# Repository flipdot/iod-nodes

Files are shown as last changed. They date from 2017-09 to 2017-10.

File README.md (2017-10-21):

# iod-nodes

ESP8266 based MQTT nodes controlled by Attiny.

This project covers battery powered WiFi devices running MQTT. The design goal was extremely low standby current for very long battery life.

The Attiny 25 in deep sleep consumes 120 nA. An interrupt on port change (mechanical switch) starts the Attiny which then switches on the Vcc of the ESP8266 via an MOSFET. After successfully connecting the WiFi and the MQTT broker and transmitting the current status the ESP8266 is shut down and the Attiny goes back into deep sleep.
The circuit supports supply by three Eneloop accumulators as well as by two alkaline primary cells.

internet of dings node with esp8266

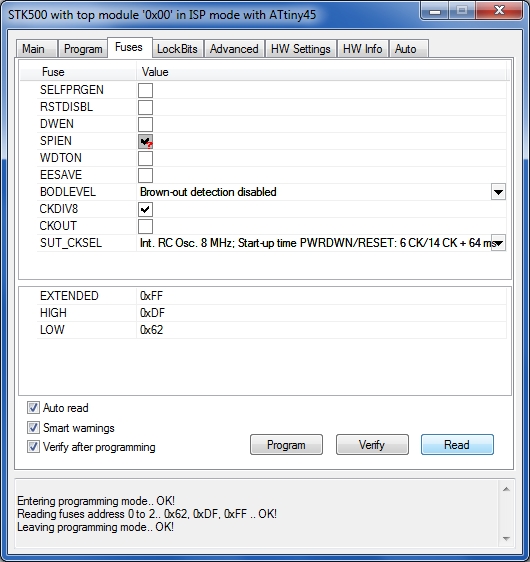
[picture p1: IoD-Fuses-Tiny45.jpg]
Fuse Settings


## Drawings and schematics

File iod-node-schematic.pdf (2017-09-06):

# ●❄❍●❄❍P▼❍P▼❍❊◗❘✺❍❊◗❘✺❍❅❆❇❆P❅❆❇❆P❉❊❊❉❊❊

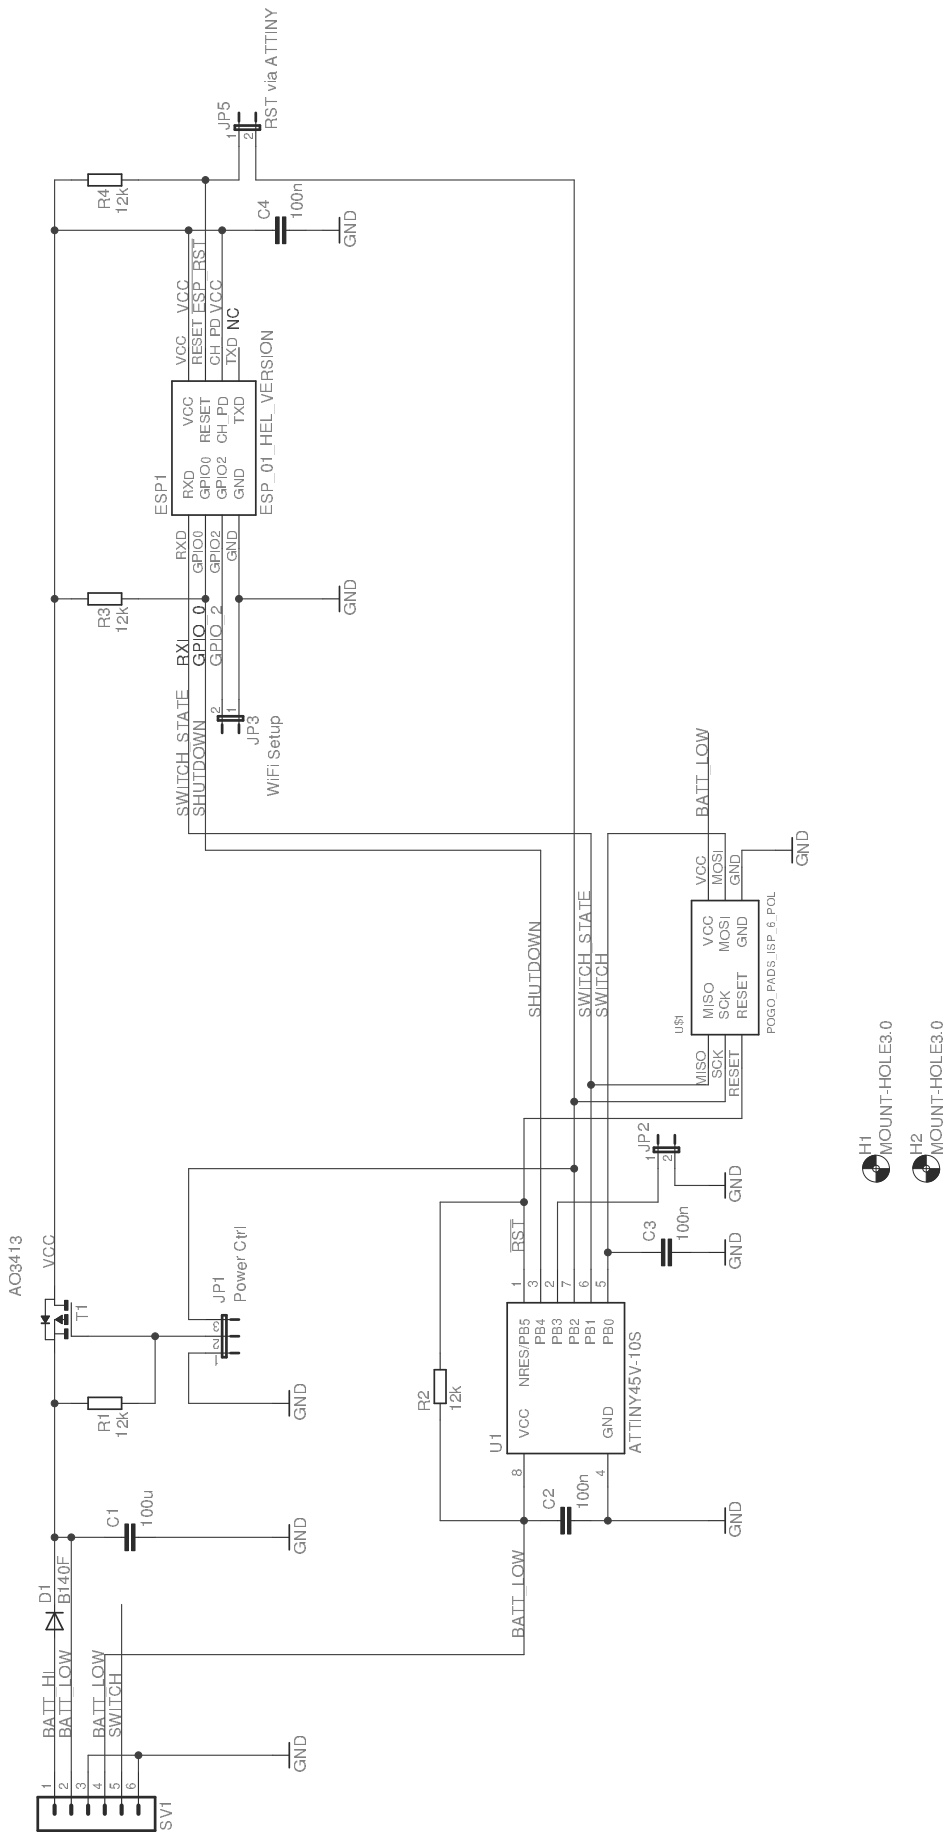
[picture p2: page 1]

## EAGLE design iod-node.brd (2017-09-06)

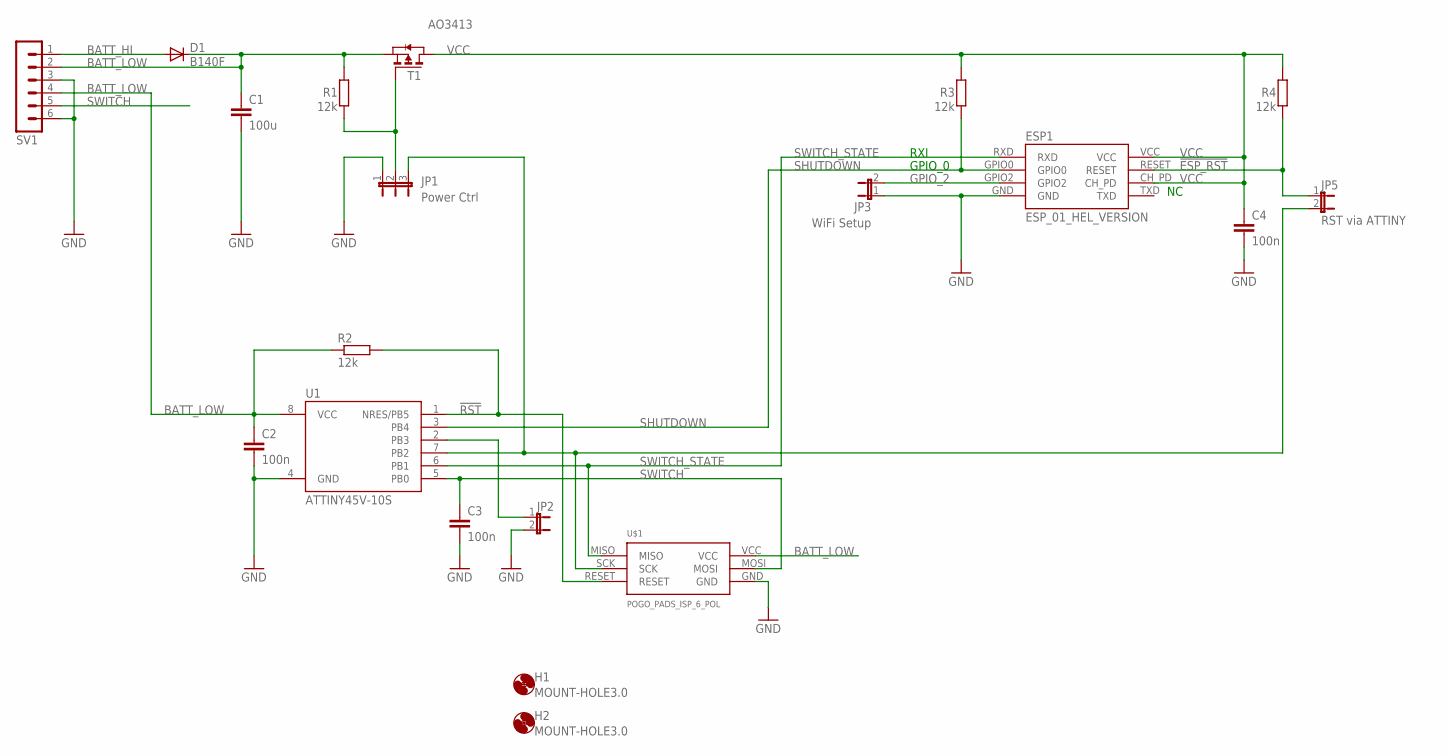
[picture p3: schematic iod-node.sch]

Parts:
C1: 100u; C1210
C2, C3, C4: 100n; C3225
D1: B140F; DO214AA
ESP1: ESP_01_HEL_VERSION; CUSTOM_ESP01_FOR_HEL
H1, H2: MOUNT-HOLE3.0; 3,0
JP1: Power Ctrl; JP2
JP2: JP1E; JP1
JP3: WiFi Setup; JP1
JP5: RST via ATTINY; JP1
R1, R2, R3, R4: 12k; R0805
SV1: MA06-1
T1: AO3413; SOT-23
U1: ATTINY45V-10S; SOIC8_EIAJ_208MIL
U$1: POGO_PADS_ISP_6_POL

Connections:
!ESP_RST: ESP1.RESET, JP5.1, R4.1
!RST: R2.2, U1.1 (NRES/PB5), U$1.RESET
BATT_HI: D1.A, SV1.1
BATT_LOW: C1.1, C2.1, D1.C, R1.2, R2.1, SV1.2, SV1.4, T1.2 (S), U1.8 (VCC), U$1.VCC
GND: C1.2, C2.2, C3.2, C4.2, ESP1.GND, JP1.1, JP2.2, JP3.1, SV1.3, SV1.6, U1.4 (GND), U$1.GND
GPIO_2: ESP1.GPIO2, JP3.2
unnamed: JP2.1, U1.2 (PB3)
unnamed: JP1.2, R1.1, T1.3 (G)
unnamed: JP1.3, JP5.2, U1.7 (PB2), U$1.SCK
SHUTDOWN: ESP1.GPIO0, R3.1, U1.3 (PB4)
SWITCH: C3.1, SV1.5, U1.5 (PB0), U$1.MOSI
SWITCH_STATE: ESP1.RXD, U1.6 (PB1), U$1.MISO
VCC: C4.1, ESP1.CH_PD, ESP1.VCC, R3.2, R4.2, T1.1 (D)

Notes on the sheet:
RXI
GPIO_0

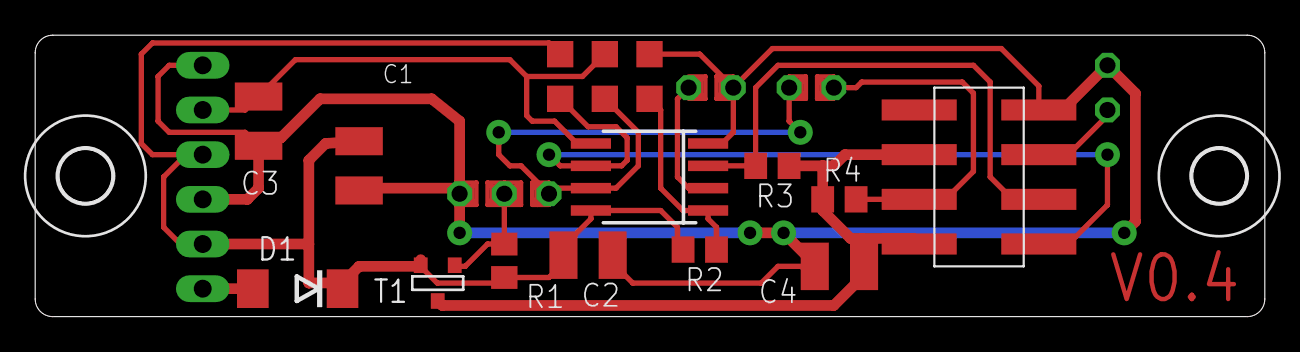
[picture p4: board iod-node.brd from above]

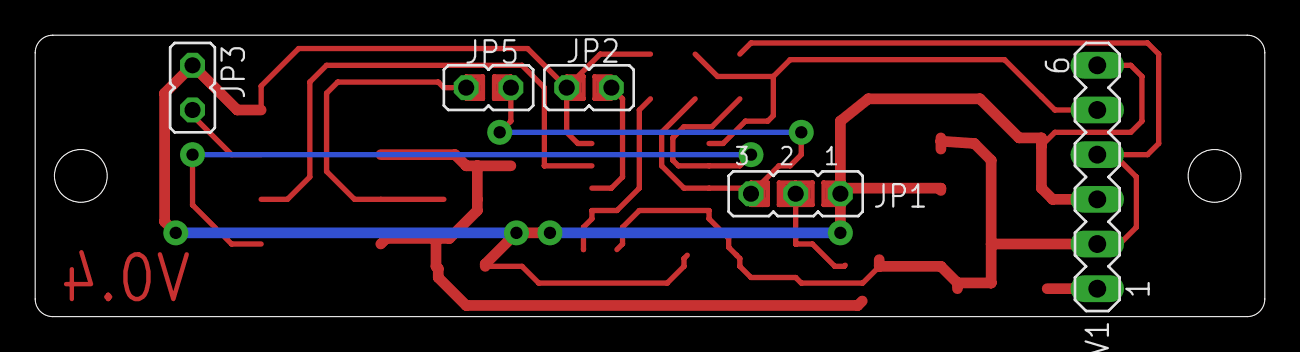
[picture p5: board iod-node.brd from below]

Board: 2 copper layers, 69.9 x 16.0 mm, 20 parts (5 on the bottom side), 13 nets.

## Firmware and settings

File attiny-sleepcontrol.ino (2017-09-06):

/**************************************************************************************************************
  +
  + Quelle: https://github.com/8n1/ESP8266-Tiny-Door-and-Window-Sensor/blob/master/Firmware/ATtiny%20Arduino%20Sketch/tiny-vreg-controller/tiny-vreg-controller.ino
  +  Fuses:            -U lfuse:w:0x62:m -U hfuse:w:0xdf:m -U efuse:w:0xff:m  (default value)

  +
  +  Getestet mit der Arduino IDE v1.6.13
  +  Voraussetzung zum kompilieren: ATtiny unterstützung ist installiert.
  +  (Am besten über den neuen Boards Manager machen: Tools->Board:...->Boards Manager->"attiny")
  +
  +  Pinout:
  +                   +-------------+
  +                 +-+ (PB5)   VCC +-+  BATT_LOW (Batteriespannung ueber Schottkyy-Diode)
  +                   | (Reset)     |
  +                   |             |
  +  DEBUG_LED      +-+ PB3     PB2 +-+  ESP_OFF (OUTPUT)
  +  (OUTPUT)         |             |
  +                   |             |
  +  SHUTDOWN       +-+ PB4     PB1 +-+  SWITCH_STATE (OUTPUT)
  +  (INPUT)          |             |
  +                   |             |
  +  GND            +-+ GND     PB0 +-+  SWITCH (INPUT)
  +                   +-------------+
  +
  +  Pin Funktionen:
  +  PB0 - SWITCH              - Umschalter, über den der ATtiny aus dem Tiefschlaf geweckt wird
  +  PB1 - SWITCH_STATE        - Der Zustand des Schalters wird für den ESP an diesem Pin ausgegeben
  +  PB2 - ESP_OFF             - Gate des MOSFET, High = ESP off, LOW = ESP on
  +  PB4 - SHUTDOWN            - Ein kurzes HIGH Signal an diesem Pin (vom ESP an den Tiny) bewirkt Abschalten des ESP und Sleep des Tiny
  +
  +  Ablauf:
  +  1. -> Der ATtiny wird durch einen PinChange(PC) Interrupt (Wechsel sowohl von HIGH nach LOW als auch umgekehrt möglich) am Pin PB0 geweckt.
  +  2. -> Der Tiny setzt PB2 auf LOW und aktiviert den MOSFET (und somit den ESP).
  +  3. -> Jetzt wird gewartet bis (vom ESP) ein Signal über PB4 kommt das den ATtiny veranlasst den ESP wieder abzuschalten,
         Ausserdem wird der Zustand des Schalters(PB0) immer wieder neu eingelesen und über PB1 ausgegeben.
  +  4. -> Ist nach "timerInterval" Sekunden noch kein Signal gekommen wird der ESP vom ATtiny wieder abgeschaltet -> PB2 geht auf HIGH
  +        Zusätzlich wird auch PB1 auf LOW gesetzt
  +  5. -> Zu guter letzt geht der ATtiny wieder in den Tiefschlaf(Power-down) und wartet auf den nächsten Interrupt.
  +        Der Stromverbrauch des ATtiny liegt während er schläft bei ca. ~300nA @3.8V. Im Datenblatt steht genauers.
  +
**************************************************************************************************************/

// Attiny-Sleepcontrol-0057.ino


#include <avr/sleep.h>

//------------------------------------------------------------------------------
// Pin Konfiguration
const int SWITCH = 0;               // PB.0
const int SWITCH_STATE = 1;         // PB.1
const int ESP_OFF = 2;              // PB.2
const int DEBUG_LED = 3;            // PB.3 
const int SHUTDOWN = 4;             // PB.4

// Anzahl Sekunden nach denen der ESP automatisch wieder abgeschaltet wird, wenn der ESP kein Abschaltsignal geliefert hat
const unsigned long timerInterval = 20;

// Arbeitsvariablen
unsigned long start_time;
boolean goto_sleep = true;
int switch_state_old;


//------------------------------------------------------------------------------
// PinChange ISR - Einstiegspunkt nach dem Tiefschlaf

ISR (PCINT0_vect) {
    PCMSK &= ~(1 << PCINT0);                                // Port Change Interrupts vorübergehend verbieten
    sleep_disable();                                        // Schlafmodus deaktivieren
    digitalWrite(DEBUG_LED, HIGH);                          // Timer und Funktionen, die Timer benutzen
    delayMicroseconds(500);                                 // können in der ISR nicht benutzt werden,
    digitalWrite(DEBUG_LED, LOW);                           // also z.B. delay() und serielle Schnittstelle
    delayMicroseconds(500);
    digitalWrite(DEBUG_LED, HIGH);
    delayMicroseconds(500);
    digitalWrite(DEBUG_LED, LOW);
    delayMicroseconds(500);
  }


//------------------------------------------------------------------------------
// SETUP FUNCTION
void setup()
{
  // GPIOs konfigurieren
  pinMode(ESP_OFF, OUTPUT);
  pinMode(SHUTDOWN, INPUT);
  pinMode(SWITCH_STATE, OUTPUT);
  pinMode(SWITCH, INPUT);                                   // SWITCH input bekommen keinen pullup, da Wechselschalter angeschlossen wird. Pullup würde unnoetigen Strom ziehen
  pinMode(DEBUG_LED, OUTPUT);
  digitalWrite(DEBUG_LED, LOW);                             // Pullup Widerstand für den unbenutzen Pin: Floating vermeiden (Stromverbrauch!)

  ADCSRA &= ~(1 << ADEN);                                   // AD Wandler abschalten (benötigt nur unnötig Strom, ~230µA)
  set_sleep_mode(SLEEP_MODE_PWR_DOWN);                      // Schlafmodus(Power-down) konfigurieren
  GIMSK |= (1 << PCIE);                                     // PinChange(PC) Interrupts erlauben
                                                            // GIMSK = General Interrupt Mask Register
                                                            // Bit    7   6   5   4   3   2   1   0
                                                            //        - INT0 PCIE -   -   -   -   -   
                                                            // GIMSK = GIMSK OR 32 = PCIE wird "1" gesetzt
}


//------------------------------------------------------------------------------
// MAIN LOOP
void loop()
{
  if (goto_sleep == true)                                   // Flag für schlafen gehen gesetzt?
  {
    digitalWrite(SWITCH_STATE, LOW);                        // SWITCH_STATE beim Schlafen auf LOW setzen, weil dieser Pin einen spannungslosen ESP
                                                            // treibt, bei HIGH => Spannung am IO-Port > Vcc, das ist nicht erlaubt
    digitalWrite(ESP_OFF, HIGH);                            // ESP abschalten


    digitalWrite(DEBUG_LED, HIGH);                          
    delayMicroseconds(100);                                
    digitalWrite(DEBUG_LED, LOW);                          
    delayMicroseconds(100);
    digitalWrite(DEBUG_LED, HIGH);
    delayMicroseconds(100);
    digitalWrite(DEBUG_LED, LOW);
    delayMicroseconds(100);
    digitalWrite(DEBUG_LED, HIGH);
    delayMicroseconds(100);
    digitalWrite(DEBUG_LED, LOW);
    delayMicroseconds(100);

    
    PCMSK |= (1 << PCINT0);                                 // Port Change Interrupt an PB0erlauben
    sleep_enable();                                         // Schlafmodus aktivieren
    sleep_mode();                                           // Tiefschlaf aktivieren und auf den Port Change Interrupt warten

//------------------------------------------------------------------------------
// STARTPUNKT nach Interrupt

    // Kommt der Port Change Interrupt (Schalter wurde betätigt), wird die Port Change ISR ausgeführt, und der ATtiny ist wieder wach,
    // anschließend geht es hier weiter
    digitalWrite(DEBUG_LED, HIGH);                          
    delayMicroseconds(250);                                
    digitalWrite(DEBUG_LED, LOW);                          
    delayMicroseconds(250);
    digitalWrite(DEBUG_LED, HIGH);
    delayMicroseconds(250);
    digitalWrite(DEBUG_LED, LOW);
    delayMicroseconds(250);
   
    digitalWrite(ESP_OFF, LOW);                             // ESP einschalten
    start_time = millis();                                  // Startzeit einlesen    
    delay(100);                                             // Entprellen
    digitalWrite(SWITCH_STATE, digitalRead(SWITCH));        // Zustand des Schalters(PB0) auf PB1 für ESP ausgeben
    switch_state_old = digitalRead(SWITCH);                 // Schalterstellung beim Aufwecken merken        
    delay(400);                                             // Nötig, weil der Pullup am esp anfangs die shutdown Leitung noch auf HIGH zieht. (Schaltungs-Design-Fehler)
                                                            // wenn der ESP gestartet ist, dann zieht er shutdown auf LOW                                                    
    goto_sleep = false;                                     // Tiny wurde gerade geweckt, also jetzt nicht schlafen, sondern mit ESP arbeiten
  }

  if (millis() - start_time >= timerInterval * 1000)        // Verfügbare Zeit abgelaufen (Weil ESP keinen Shutdown angefordert hat)?
  {
    goto_sleep = true;                                      // Im nächsten Durchlauf von loop wieder schlafen gehen
  }

  if (digitalRead(SHUTDOWN) == 1)                           // Shutdown Anforderung vom ESP erkannt ?
  {
    if (switch_state_old == digitalRead(SWITCH))            // Schalterstellung ist unverändert, übertragener Status ist gültig
    {
      goto_sleep = true;
    }
    else                                                    // Schalterstellung hat sich während der übertragung des Statusses geändert, neu senden 
    {
      digitalWrite(ESP_OFF, HIGH);                          // ESP ausschalten 
      delay(5000);     
      start_time = millis();                                // Startzeit einlesen    
      digitalWrite(ESP_OFF, LOW);                           // ESP einschalten, und geänderte Schalterstellung übertragen
      delay(500);                                           // Nötig, weil der pullup am esp anfangs die shutdown leitung noch auf HIGH zieht. (Schaltungs-Design-Fehler)
      digitalWrite(SWITCH_STATE, digitalRead(SWITCH));      // Zustand des Schalters(PB0) auf PB1 ausgeben
      switch_state_old = digitalRead(SWITCH);               // Aktuelle Schalterstellung merken

    }
  }
}

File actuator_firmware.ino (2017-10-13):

/*
  It will reconnect to the server if the connection is lost using a blocking
  reconnect function. See the 'mqtt_reconnect_nonblocking' example for how to
  achieve the same result without blocking the main loop.


   Für Witty Cloud.
   Board: NodeMCU 1.0 ESP 12E

   Onboard LED blaues blinken: initiales WiFi Connect
   Grün: Kontakt zum Broker
   Rot: Kein Kontakt zum Broker

   auf der befehlszeile publishen:
   mosquitto_pub -h 192.168.178.81  -t 'aktoren/panel0' -m '4 1'

   und subscriben:
   mosquitto_sub -h 192.168.178.81  -t aktoren/panel0

   den Totmannkanal:
   mosquitto_sub -h 192.168.178.81  -t aliveTopic

*/

#include <ESP8266WiFi.h>
#include <PubSubClient.h>
#include <ArduinoJson.h>

const char* ssid = "security-by-iod";
const char* password = "45727545669727595";
const char* mqtt_server = "192.168.3.241";

const char* subscribeTopic = "actors/panel0";
//const char* publishTopic ="totmann/panel0";
const char* deviceName = "panel0";

// ----- definitions for WS2812 LED strings -----------------------------------------
#include <Adafruit_NeoPixel.h>
#ifdef __AVR__
#include <avr/power.h>
#endif

#define PIN 14

// Parameter 1 = number of pixels in strip
// Parameter 2 = Arduino pin number (most are valid)
// Parameter 3 = pixel type flags, add together as needed:
//   NEO_KHZ800  800 KHz bitstream (most NeoPixel products w/WS2812 LEDs)
//   NEO_KHZ400  400 KHz (classic 'v1' (not v2) FLORA pixels, WS2811 drivers)
//   NEO_GRB     Pixels are wired for GRB bitstream (most NeoPixel products)
//   NEO_RGB     Pixels are wired for RGB bitstream (v1 FLORA pixels, not v2)
//   NEO_RGBW    Pixels are wired for RGBW bitstream (NeoPixel RGBW products)
Adafruit_NeoPixel strip = Adafruit_NeoPixel(7, PIN, NEO_GRB + NEO_KHZ800);



WiFiClient espClient;
PubSubClient client(espClient);
long lastMsg = 0;
char msg[50];
int value = 0;

const int RED = 15;                 // buildt in RGB LED
const int BLUE = 13;
const int GREEN = 12;

void setup_wifi() {

  delay(10);
  // We start by connecting to a WiFi network
  Serial.println();
  Serial.print("Connecting to ");
  Serial.println(ssid);

  WiFi.begin(ssid, password);

  while (WiFi.status() != WL_CONNECTED) {
    digitalWrite(BLUE, HIGH);
    delay(100);
    digitalWrite(BLUE, LOW);
    delay(400);
    Serial.print(".");
  }

  // randomSeed(micros());

  Serial.println("");
  Serial.println("WiFi connected");
  Serial.println("IP address: ");
  Serial.println(WiFi.localIP());
}

void callback(char* topic, byte* payload, unsigned int length) {

  StaticJsonBuffer<200> jsonBuffer;
  JsonObject& json_object = jsonBuffer.parseObject(payload);

  if (!json_object.success()) {
    Serial.println("parseObject() failed");
    Serial.print("Payload: ");
    for (int i = 0; i < length; i++)
      Serial.print((char) payload[i]);

    Serial.println();
    return;
  } else {
    Serial.println("Message arrived");
    json_object.prettyPrintTo(Serial);
    int led = json_object["led_num"];
    char red = json_object["red"];
    char green = json_object["green"];
    char blue = json_object["blue"];

    if (0 <= led && led < 5) {
      strip.setPixelColor(led, red, green, blue);
      strip.show();
    }
  }
}

void reconnect() {                                            // ToDo: if too many reconnect retrys, do reboot
  // Loop until we're reconnected                             // ESP.reset(); doesn't do the job, hard reset seems to be the way
  while (!client.connected()) {
    Serial.print("Attempting MQTT connection...");
    // Create a random client ID                              // why random client ID?
    String clientId = "ESP8266Client-";
    clientId += String(random(0xffff), HEX);
    // Attempt to connect
    if (client.connect(clientId.c_str())) {
      digitalWrite(GREEN, HIGH);
      digitalWrite(RED, LOW);
      Serial.println("connected");
      // Once connected, publish an announcement...
      // client.publish(publishTopic, deviceName);
      // ... and resubscribe
      client.subscribe(subscribeTopic);
    } else {
      digitalWrite(RED, HIGH);
      digitalWrite(GREEN, LOW);
      Serial.print("failed, rc=");
      Serial.print(client.state());
      Serial.println(" try again in 5 seconds");
      // Wait 5 seconds before retrying
      delay(5000);
    }
  }
}

void setup() {
  pinMode(RED, OUTPUT);
  digitalWrite(RED, LOW);
  pinMode(GREEN, OUTPUT);
  digitalWrite(GREEN, LOW);
  pinMode(BLUE, OUTPUT);
  digitalWrite(BLUE, LOW);

  Serial.begin(115200);
  setup_wifi();
  client.setServer(mqtt_server, 1883);
  client.setCallback(callback);

  strip.begin();
  strip.show();
  delay(1000);
  strip.setPixelColor(0, 0, 0, 2);
  strip.setPixelColor(1, 0, 0, 2);
  strip.setPixelColor(2, 0, 0, 2);
  strip.setPixelColor(3, 0, 0, 2);
  strip.setPixelColor(4, 0, 0, 2);
  strip.show();

}

void loop() {

  if (!client.connected()) {
    digitalWrite(RED, HIGH);
    digitalWrite(GREEN, LOW);
    reconnect();
  }
  client.loop();
  /*
    long now = millis();
    if (now - lastMsg > 2000) {
      lastMsg = now;
      ++value;
      // snprintf (msg, 75, "hello world #%ld", value);
      snprintf (msg, 75, deviceName);
      //Serial.print("Publish message: ");
      //Serial.println(msg);
      // client.publish(publishTopic, msg);
    }
  */
}

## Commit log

2017-10-13 add actuator-firmware
2017-10-21 Fix README.md formatting, add fuse settings image
